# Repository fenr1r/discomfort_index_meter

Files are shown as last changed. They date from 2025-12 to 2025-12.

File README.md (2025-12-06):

# discomfort_index_meter
using ATtiny85.

This repo. includes 

- C++ Source codes for ATtiny85 (Atmel Studio)
- Schematic (KiCad)

Used libraries:

- Peter Fleury's I2C Master Interface [http://www.peterfleury.epizy.com/avr-software.html]

For more information please refer to my blog:

[https://vita-brevis.hatenablog.com/entry/2025/12/06/212559]

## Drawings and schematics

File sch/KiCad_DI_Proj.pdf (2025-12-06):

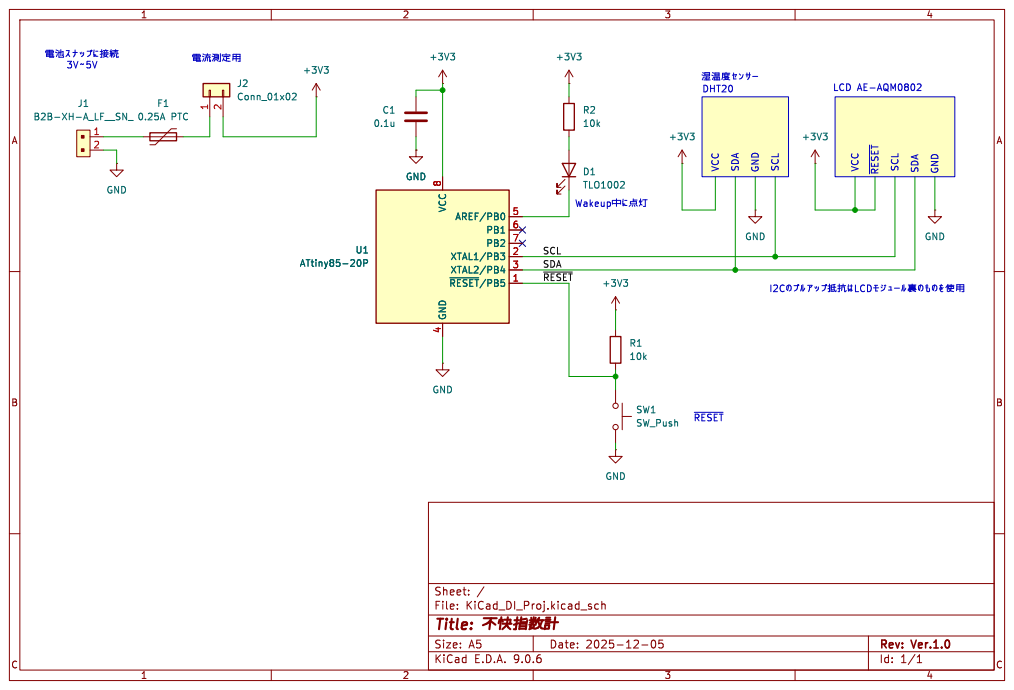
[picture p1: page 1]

þÿ–ûmAn,[šu(

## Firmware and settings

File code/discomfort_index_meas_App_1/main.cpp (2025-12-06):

/*
 * discomfort_index_meas_App_1.cpp
 *
 * Created: 2025/11/13 3:50:04
 * Author : fenrir_
 */ 

// Device Fuse bit
// WDT disabled
// OSC RC 9.6, DIV8

// Hardware connection:
//	SDA	PB4
//	SCL PB3
//	LED PB0

#include <avr/io.h>
#include <avr/interrupt.h>
#include <avr/sleep.h>
#include <stdlib.h>	// itoa
#include <string.h>

// Internal RC 8.0MHz を 8分周（1MHz）。I2Cのウェイトはnop1回でOK
#define F_CPU 1000000
#include <util/delay.h>

#include "LCD_ST7032i.hpp"
#include "DHT20.hpp"

#define _USE_TIMER_ISR 1

#ifdef _USE_TIMER_ISR
	static uint16_t timer_cnt = 0;
#endif

// 1回ずつしか呼ばれないのでinline化
static void inline LED_init(){
	DDRB |= (1 << 0);
	PORTB |= (1 << 0);
}

static void inline LED_on(){
	PORTB |= (1 << 0);
}

static void inline LED_off(){
	PORTB &= ~(1 << 0);
}

static inline SensorValue observe_temperature_and_humidity(){
	return DHT20_reflesh();
}

// 割り算を使わないように、×10した値を返す（固定小数点）
// tempは小数第1位までを整数として表す
// humidityは整数部分のみ
static inline uint16_t calculate_discomfort_index(const uint16_t temp, const uint16_t humidity){
	// 整数演算とするため、一旦×100000する
	return (uint16_t)((81 * 100 * (uint32_t)temp + (1 * (uint32_t)humidity * (99 * (uint32_t) temp - 14300))) / 10000) + 463;
}

static inline void display_temperature_humidity_and_discomfort_index(const uint8_t temp, const uint8_t humidity, const uint16_t di){

	char temp_buf[6];
	itoa(temp, temp_buf, 10);
	
	// itoaは左詰め等の指定ができないので、strlenで調整
	// 温度が1桁台の場合のみ考慮
	// 本当はsprintfで整形したほうがいい。それか、自前itoa
	if (strlen(temp_buf) == 2){
		temp_buf[2] = temp_buf[1];
		temp_buf[1] = temp_buf[0];
		temp_buf[0] = '0';
	}
	
	temp_buf[3] = temp_buf[2];
	temp_buf[2] = '.';
	temp_buf[4] = 0b11011111;	// °の記号
	temp_buf[5] = '\0';			// lcd_putsは終端文字は表示しない
	
	lcd_puts(LCD_ST7032I_RAMADDR_ROW1, temp_buf, true);
	
	char humidity_buf[4];
	itoa(humidity, humidity_buf, 10);
	humidity_buf[2] = '%';
	humidity_buf[3] = '\0';
		
	lcd_puts(LCD_ST7032I_RAMADDR_ROW1, humidity_buf, false);
	
	char di_buf[5];
	itoa(di, di_buf, 10);
	
	di_buf[3] = di_buf[2];
	di_buf[2] = '.';
	di_buf[4] = '\0';
	
	lcd_puts(LCD_ST7032I_RAMADDR_ROW2, "DI:", true);
	lcd_puts(LCD_ST7032I_RAMADDR_ROW2, di_buf, false);
}

#ifdef _USE_TIMER_ISR

// 割り込みは、1MHz / 1024（タイマのプリスケーラ） / 256（TCNT0の最大カウント） ≒ 0.262sごとに生じる
ISR(TIM0_OVF_vect){
	// 他に割り込み来ないけど、一応disableしておく
	cli();
	
	timer_cnt++;
	
	// 5sごとに測定する（5 / 0.262 ≒ 19）
	if (timer_cnt > 19){
		timer_cnt = 0;
		
		// update
		LED_on();
		
		const SensorValue sensor_val = observe_temperature_and_humidity();
		
		const uint16_t di = calculate_discomfort_index(sensor_val.temperature, sensor_val.humidity);
		
		display_temperature_humidity_and_discomfort_index(sensor_val.temperature, sensor_val.humidity, di);
		
		LED_off();
	}
	
	sei();
}

static void init_timer(){
	timer_cnt = 0;
	
	TCCR0A	= 0x00;			// Normalモード、コンペア出力なし
	TCCR0B	= 0b00000101;	// 1024分周（1MHz / 1024 ≒ 1kHz）
	TIMSK	= (1 << TOIE0);	// Enable Overflow Interrupt
}
#endif

int main(void)
{
    // SCL, SDA、LEDポートはinitで上書きされる。が、とりあえず最初は全入力全プルアップ
	DDRB = 0x00;
	PORTB = 0x3F;
		
	ACSR &= ~(1 << ACD);	// アナログ・コンパレータを非アクティブ（電力消費軽減）
	
	PRR = (1 << PRTIM1) | (1 << PRUSI) | (1 << PRADC);	// Timer1, USI, ADCを非アクティブ
	
	// 各種初期化
	LED_init();
	lcd_init();
	DHT20_init();
	
	LED_off();
	
	// 本当は割り込みを使いたいが、使うと+200Bくらいされ、1kBを超えてしまうためdisable
#ifdef _USE_TIMER_ISR
	init_timer();
	sei();	
	
	// IdleよりPower-downのほうが省電力だが、どちらにしろLCDが1mAくらい、温度センサーが10mAくらい消費するため、Idleでよしとした。
	// Power-downはWDTかINT割り込みが必要だが、IdleならTimerで起きるので扱いやすいし
	set_sleep_mode(SLEEP_MODE_IDLE);
	
	while (1)
	{
		// Timer割り込みを使う場合、メインループではIdleモードに落とす
		sleep_mode();
	}
#else
	while (1)
	{
		// Timer割り込みしない場合、ひたすらポーリングで値更新	
		_delay_ms(1000);
			
		LED_on();
			
		const SensorValue sensor_val = observe_temperature_and_humidity();
			
		const uint16_t di = calculate_discomfort_index(sensor_val.temperature, sensor_val.humidity);
			
		display_temperature_humidity_and_discomfort_index(sensor_val.temperature, sensor_val.humidity, di);
			
		LED_off();
	}
#endif
	
	return 0;
}

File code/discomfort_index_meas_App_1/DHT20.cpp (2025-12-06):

/*
 * DHT20.cpp
 *
 * Created: 2025/11/17 12:36:24
 *  Author: fenrir_
 */ 

#include <avr/io.h>
#include <stdlib.h>	// itoa

#define F_CPU 1000000
#include <util/delay.h>

#include "i2cmaster.h"
#include "DHT20.hpp"

#define CODE_SHORT 1
//#define _DEBUG 1

#ifdef _DEBUG

#include "LCD_ST7032i.hpp"
#include <stdio.h>	//sprintf

#endif


void DHT20_init(){

#ifndef CODE_SHORT
	// LCD側で200ms先に待つので、省略可能
	_delay_ms(100); 
#endif
	
	uint8_t status_word = 0;
	
	i2c_start(0x71);
	status_word = i2c_read(0);
	i2c_stop();
	
#ifndef CODE_SHORT
	if (status_word != 0x18) {
		// TODO : init 0x1B, 0x1C, 0x1E
		// しかし、公式のサンプルコード見に行かないと処理が分からない
		// 幸い、今のところはずっと初期化後0x18（=24）が返ってきている
	}
#endif

#ifdef _DEBUG
	char buf[5];
	itoa(status_word, buf, 10);
	lcd_puts(LCD_ST7032I_RAMADDR_ROW1, buf, true);
#endif
}

// 温度がマイナスの場合は面倒だから考慮しない
SensorValue DHT20_reflesh()
{
	
#ifndef CODE_SHORT
	// main側で10ms待つので、省略可能
	_delay_ms(10);
#endif
	
	// 計測開始コマンドをWrite
	i2c_start(0x70);
	i2c_write(0xAC);
	i2c_write(0x33);
	i2c_write(0x00);
	i2c_stop();
	
	// 80ms待つ（省略不能）
	_delay_ms(80);
	
	// 計測結果読み取り
	
	SensorValue ret;

	uint8_t state;
	uint8_t data[5];
	
	i2c_start(0x71);
	state = i2c_read(1);
	data[0] = i2c_read(1);
	data[1] = i2c_read(1);
	data[2] = i2c_read(1);
	data[3] = i2c_read(1);
	data[4] = i2c_read(1);
	i2c_read(0);	// CRC 使わない
	i2c_stop();
	
#ifndef CODE_SHORT
	uint32_t _temp = 0;	// 本当はsigned だが、0℃は下回らない前提
	uint32_t _humidity = 0;
	
	_humidity = ((uint32_t)data[0] << 12) | ((uint32_t)data[1] << 4) | (uint32_t)((data[2] & 0xF0) >> 4);
	_temp = ((uint32_t)(data[2] & 0x0F) << 16) | ((uint32_t)data[3] << 8) | (uint32_t)(data[4]);
	
	// 10進、固定小数点（小数第1位まで含んで整数として扱う）の値に直す
	_humidity = ((_humidity * 10 * 100) >> 20);	// 2^20 * 1000 = 1,048,576,000 < 2^20 * 2^10 = 2^30 < 2^32 なのでuint32_tに収まる
	_temp = ((_temp * 10 * 200) >> 20) - 50 * 10;	// リッチな書き方
	
	// 範囲外チェック
	if (_humidity > 1000) {
		_humidity = 999;
	}
	
	if (_temp > 1500) {
		_temp = 1499;
	}
	// else if (humidity2 < 0) {
	//	humidity2 = 0;
	//}
	
	// 最後に幅合わせ
	ret.humidity	= (uint16_t)_humidity;	
	ret.temperature	= (uint16_t)_temp;
#else
	// 測定される湿度をAとする
	// Aの上位n-bitのみを使用すると、測定は1 / 2^nの分解能を持つ
	// 例：	n = 20	0.009%
	//		n = 12	0.02%
	//		n = 10	0.10%
	//		n = 9	0.20%
	//		n = 8	0.40%
	//		n = 6	1.56%
	// 実際のところ、このセンサーの湿度の誤差は最小でも+/- 3%なので、n = 6程度の精度があればよいことになる。
	// ただし、表示上の1の位すらも雑というのはなんだか気に食わないので、n = 9で使う。
	// 
	// %単位にしたときの整数だけ使いたいなら、×100。
	// その場合、(A * 100) / 2^nの順で計算する。先に/2^nすると小数になり計算結果は切り捨てられすべて0となる。
	// このとき、計算過程における最大値はフルスケール時の2^n * 100なので、それに応じたbit幅が必要。
	// 2^6 < 100 < 2^7なので、(n + 7) bitあればいい。
	// 例：	n = 10	-> 102400 < 2^17 = 131072 よって uint16_tではダメでuint32_t
	// 例：	n = 9	-> 51200  < 2^16 = 65536  よって uint16_tでOK
	// 
	// %単位にしたときに小数第1位まで使いたいなら、(A * 1000) / 2^nする。しかし実用的ではない
	// 
	// 温度は、精度+/-0.5℃で、換算式が×100から×200になるので（更に、小数表示のためには×2000）、uint32_tを使うのが無難
	// 
	// 結局、温度のためにuint32_t使うなら湿度もuint32_tでもよいような…
	
	uint32_t _temp = 0;
	uint16_t _humidity = 0;
	
	_humidity = ((uint32_t)data[0] << 1) | (uint32_t)((data[2] & 0x80) >> 7);
	_temp = ((uint32_t)(data[2] & 0x0F) << 16) | ((uint32_t)data[3] << 8) | (uint32_t)(data[4]);
	
	// 10進の値に直す
	_humidity = ((_humidity * 100) >> 9);	// 10進、整数
	_temp = ((_temp * 2000) >> 20) - 500; // 10進、固定小数点（小数第1位まで含んで整数として扱う）
	
	// 範囲外チェック
	if (_humidity > 100) {
		_humidity = 99;
	}
	
	if (_temp > 1500) {
		_temp = 1499;
	}
	
	// 最後に幅合わせ
	ret.humidity	= _humidity;
	ret.temperature	= (uint16_t)_temp;
#endif
	
#ifdef _DEBUG
	char buf[8];
	sprintf(buf, "%x %u", state, _humidity);
	// sprintf(buf, "%x", temp);
	
	lcd_puts(LCD_ST7032I_RAMADDR_ROW1, buf, true);
	
	//sprintf(buf, "%x %x", data[1], data[2]);
	sprintf(buf, "%u", _temp);
	lcd_puts(LCD_ST7032I_RAMADDR_ROW2, buf, true);
#endif

	return ret;
}
